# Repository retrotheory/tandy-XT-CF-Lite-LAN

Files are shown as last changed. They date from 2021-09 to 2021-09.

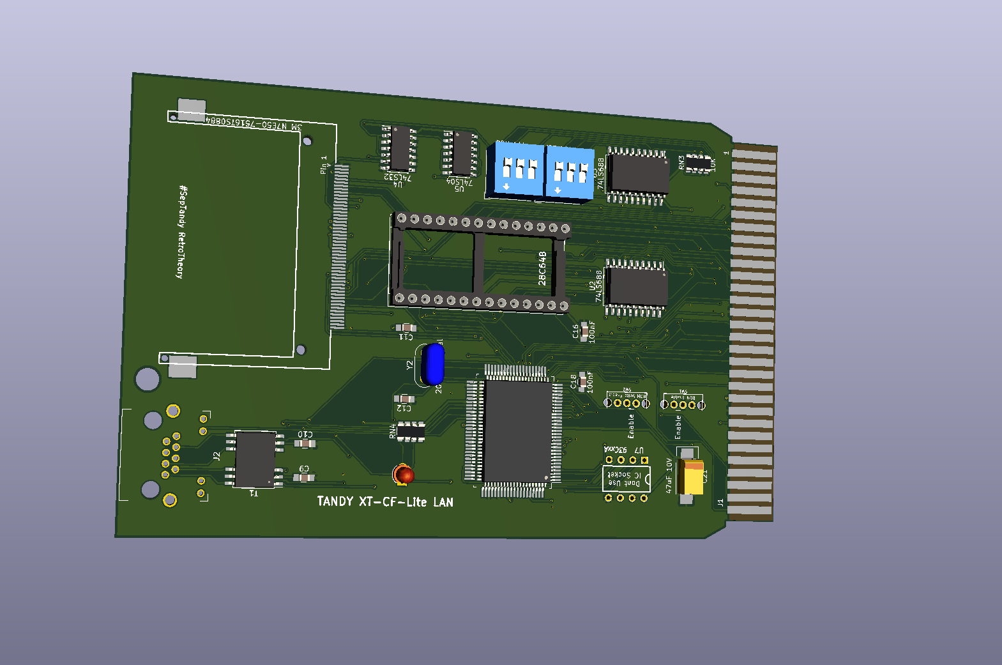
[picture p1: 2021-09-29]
Images/BoardRender.png

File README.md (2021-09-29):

Tandy XT-CF-Lite LAN Rev 0.9a ReadMe
----------------------------
This is a Compact Flash HD and Realtek LAN card for the Tandy 1400. It uses the expansion slot on the rear of the Tandy to add a bootable HD. 
The Realtek 8019AS is an NE2000 compatible. Uses the XT NE2000 packet driver. 

https://www.vcfed.org/forum/forum/genres/pcs-and-clones/41507-ne2000-packet-drivers-for-8-bit-slots

RSET8019.EXE for DOS, can set EEPROM parameters, also includes diagnostic functions

8-bit TANDY (ISA) CompactFlash interface + Boot ROM + LAN

Documentation for the switches can be found on the rear silkscreen. More ROM I/O addresses are possible than the information on the silkscreen. See below.

Credit:
-------
Design uses schematic from Sergey Kiselev, with a few small changes to switches, and PCB from scratch.\
www.malinov.com/Home/sergeys-projects/xt-cf-lite

https://www.lo-tech.co.uk/xt-cf-card-for-tandy-1400-series-laptops/
James Pearce for showing that this was possible a long long time ago.

XT-IDE Universal BIOS\
www.xtideuniversalbios.org  
www.xtideuniversalbios.org/binaries  
Use the latest working binary that includes XTIDECFG.COM (config utility), ide_xt.bin (8086/8088), ide_xtp.bin (80186/V20/V30 and up).

Further documentation:
----------------------

SW1 - ON: ROM Enabled; OFF: ROM Disabled\
SW2 - ON: EEPROM Write Enabled; OFF: EEPROM Write Disabled

---

SW3 - ROM I/O Port:  
123 ROM  
111 C0000  < Tandy Default  
110 C4000  
101 C8000  
101 CA000  
100 CC000  
011 D0000 
010 D4000  
001 D8000  
000 DC000  

Make sure that selected I/O and EEPROM addresses do not conflict with other devices.
Addresses 0xC0000 - 0xC6000 will conflict with EGA/VGA BIOS extension.
Addresses 0xC8000 - 0xCA000 might conflict with XT Hard Disk BIOS extension.
Addresses 0xE0000 and up might conflict with system BIOS on newer motherboards.
It is recommended to disable EEPROM write once XT IDE BIOS extension is programmed and configured.

---

SW4 - IDE I/O Port:  
123 IDE  
111 300 < Default  
011 320  
101 340  
001 360  
110 380  
010 3A0  
100 3C0  
000 3E0  

---

LAN 
Realtek 8019AS 93LC46 EEPROM
Due to height restrictions in the Tandy expansion bay, dont use an IC socket for the U7 93CXX   (93LC46)

---

| References | Value | Footprint | Quantity Per PCB |
|---|---|---|---|
| C1 C2 C3 C4 C5 C6 C15 C16 C17 C18 C19 | 100nF | C_0805_HandSoldering | 11 |
| C20 | 100nF | C_0805_HandSoldering | 1 |
| C7 C8 | 10uF | C_0805_HandSoldering | 2 |
| C21 | 47uF 10V | CP_Tantalum_Case-D_EIA-7343-31_Hand | 1 |
| C9 C10 C11 C12 C13 C14 | C | C_0805_HandSoldering | 6 |
| D1 | IDE LED | LED_D3.0mm | 1 |
| J2 | RJ45_LED_Shielded | 8P8C_yellow_green_Ckmtw_C133529 | 1 |
| J1 | Tandy_PCBEdgeBus_02x30 | Connector_PCBEdge_Tandy1400LT | 1 |
| P1 | CF_CARD | CF_Slot_3M_N7E50-7516TS0884 | 1 |
| P2 | IDE LED | PinHeader_1x02_P2.54mm_Horizontal | 1 |
| R3 | 200R | R_0805_HandSoldering | 1 |
| R5 R6 | 1K | R_0805_HandSoldering | 2 |
| R1 | 5.6k | C_0805_2012Metric_Pad1.15x1.40mm_HandSolder | 1 |
| R2 | 10K | C_0805_2012Metric_Pad1.15x1.40mm_HandSolder | 1 |
| R7 | 10K | R_0805_HandSoldering | 1 |
| R4 | 27k | R_0805_HandSoldering | 1 |
| RN1 RN2 RN3 | 10K | R_Array_Convex_4x1206 | 3 |
| RN4 | 1K | R_Array_Convex_4x1206 | 1 |
| SW4 | IDE Addr | SW_DIP_SPSTx03_Slide_9.78x9.8mm_W7.62mm_P2.54mm | 1 |
| SW3 | ROM Addr | SW_DIP_SPSTx03_Slide_9.78x9.8mm_W7.62mm_P2.54mm | 1 |
| SW1 | ROM Enable | CKCOMP-OS102011MA1QN1 | 1 |
| SW2 | ROM Write Enable | CKCOMP-OS102011MA1QN1 | 1 |
| T1 | 13F-39MNL | SOIC-16W-12_7.5x10.3mm_P1.27mm | 1 |
| U1 | 28C64 | DIP-28_W15.24mm_Socket | 1 |
| U5 | 74LS04 | SOIC-14_3.9x8.7mm_P1.27mm | 1 |
| U4 | 74LS32 | SOIC-14_3.9x8.7mm_P1.27mm | 1 |
| U2 U3 | 74LS688 | SOIC-20W_7.5x12.8mm_P1.27mm | 2 |
| U7 | 93CxxA | IC_DIP8_300 | 1 |
| U6 | RTL8019AS | LQFP-14x20mm_P0.5mmRealtek | 1 |
| Y2 | 20Mhz Crystal | Resonator-2pin_w8.0mm_h3.5mm | 1 |

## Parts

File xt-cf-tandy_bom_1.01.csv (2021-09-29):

Component | Description | Part | References | Value | Footprint | Quantity Per PCB | Datasheet
1 |  | C-xt-cf-rescue | C1 C2 C3 C4 C5 C6 C15 C16 C17 C18 C19 | 100nF | C_0805_HandSoldering | 11
2 | Unpolarized capacitor | C | C20 | 100nF | C_0805_HandSoldering | 1 | ~
3 |  | CP1-xt-cf-rescue | C7 C8 | 10uF | C_0805_HandSoldering | 2
4 | Unpolarized capacitor | C | C21 | 47uF 10V | CP_Tantalum_Case-D_EIA-7343-31_Hand | 1 | ~
5 | Unpolarized capacitor | C | C9 C10 C11 C12 C13 C14 | C | C_0805_HandSoldering | 6 | ~
6 | Light emitting diode | LED | D1 | IDE LED | LED_D3.0mm | 1
7 |  | RJ45_LED_Shielded | J2 | RJ45_LED_Shielded | 8P8C_yellow_green_Ckmtw_C133529 | 1
8 | Generic connector, single row, 01x30, script generated (kicad-library-utils/schlib/autogen/connector/) | Tandy_PCBEdgeBus_02x30 | J1 | Tandy_PCBEdgeBus_02x30 | Connector_PCBEdge_Tandy1400LT | 1 | ~
9 |  | CF_CARD-xt-cf-rescue | P1 | CF_CARD | CF_Slot_3M_N7E50-7516TS0884 | 1
10 |  | CONN_2-xt-cf-rescue | P2 | IDE LED | PinHeader_1x02_P2.54mm_Horizontal | 1
11 | Resistor | R | R3 | 200R | R_0805_HandSoldering | 1 | ~
12 | Resistor | R | R5 R6 | 1K | R_0805_HandSoldering | 2 | ~
13 |  | R-xt-cf-rescue | R1 | 5.6k | C_0805_2012Metric_Pad1.15x1.40mm_HandSolder | 1
14 |  | R-xt-cf-rescue | R2 | 10K | C_0805_2012Metric_Pad1.15x1.40mm_HandSolder | 1
15 | Resistor | R | R7 | 10K | R_0805_HandSoldering | 1 | ~
16 | Resistor | R | R4 | 27k | R_0805_HandSoldering | 1 | ~
17 | 4 resistor network, parallel topology | R_Pack04 | RN1 RN2 RN3 | 10K | R_Array_Convex_4x1206 | 3 | ~
18 | 4 resistor network, parallel topology | R_Pack04 | RN4 | 1K | R_Array_Convex_4x1206 | 1 | ~
19 | 3x DIP Switch, Single Pole Single Throw (SPST) switch, small symbol | SW_DIP_x03 | SW4 | IDE Addr | SW_DIP_SPSTx03_Slide_9.78x9.8mm_W7.62mm_P2.54mm | 1
20 | 3x DIP Switch, Single Pole Single Throw (SPST) switch, small symbol | SW_DIP_x03 | SW3 | ROM Addr | SW_DIP_SPSTx03_Slide_9.78x9.8mm_W7.62mm_P2.54mm | 1
21 | Switch, single pole double throw | SW_SPDT | SW1 | ROM Enable | CKCOMP-OS102011MA1QN1 | 1
22 | Switch, single pole double throw | SW_SPDT | SW2 | ROM Write Enable | CKCOMP-OS102011MA1QN1 | 1
23 |  | 13F-39MNL | T1 | 13F-39MNL | SOIC-16W-12_7.5x10.3mm_P1.27mm | 1
24 |  | 28C64-xt-cf-rescue | U1 | 28C64 | DIP-28_W15.24mm_Socket | 1
25 |  | 74LS04-xt-cf-rescue | U5 | 74LS04 | SOIC-14_3.9x8.7mm_P1.27mm | 1
26 |  | 74LS32-xt-cf-rescue | U4 | 74LS32 | SOIC-14_3.9x8.7mm_P1.27mm | 1
27 |  | 74LS688-xt-cf-rescue | U2 U3 | 74LS688 | SOIC-20W_7.5x12.8mm_P1.27mm | 2
28 | Serial EEPROM, 93 Series, 5.0V, DIP-8/SOIC-8 | 93CxxA | U7 | 93CxxA | IC_DIP8_300 | 1 | http://ww1.microchip.com/downloads/en/DeviceDoc/20001749K.pdf
29 |  | RTL8019AS | U6 | RTL8019AS | LQFP-14x20mm_P0.5mmRealtek | 1
30 | Two pin crystal | Crystal | Y2 | 20Mhz Crystal | Resonator-2pin_w8.0mm_h3.5mm | 1 | ~
Component Groups: | 30
Component Count: | 50
Fitted Components: | 50
Number of PCBs: | 1
Total components: | 50
Schematic Version: | 1.01
Schematic Date: | 2021-09-29
PCB Variant: | default
BoM Date: | 29/09/2021 14:19:13
Schematic Source: | xt-cf-tandy.sch
KiCad Version: | Eeschema (5.1.6)-1

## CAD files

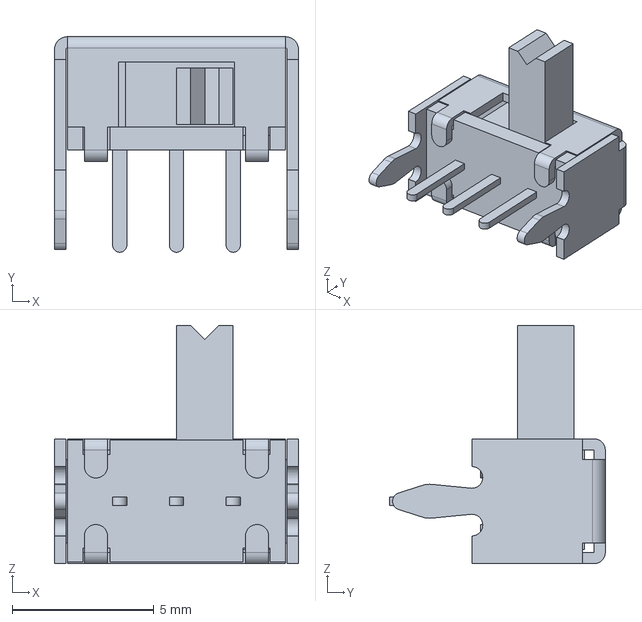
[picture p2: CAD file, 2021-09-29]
3Dmodels/OS102011MA1QN1.stp
8.60 x 7.60 x 8.40 mm

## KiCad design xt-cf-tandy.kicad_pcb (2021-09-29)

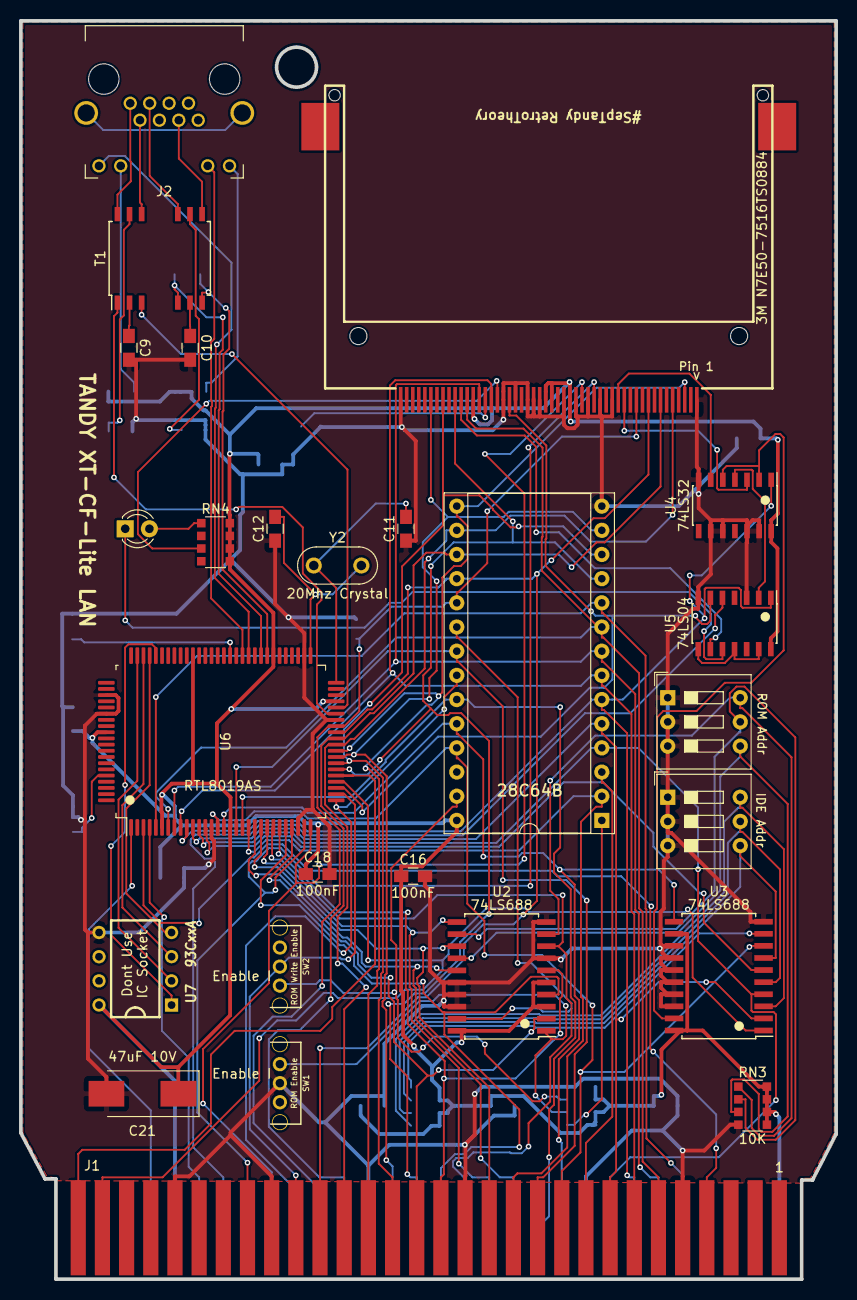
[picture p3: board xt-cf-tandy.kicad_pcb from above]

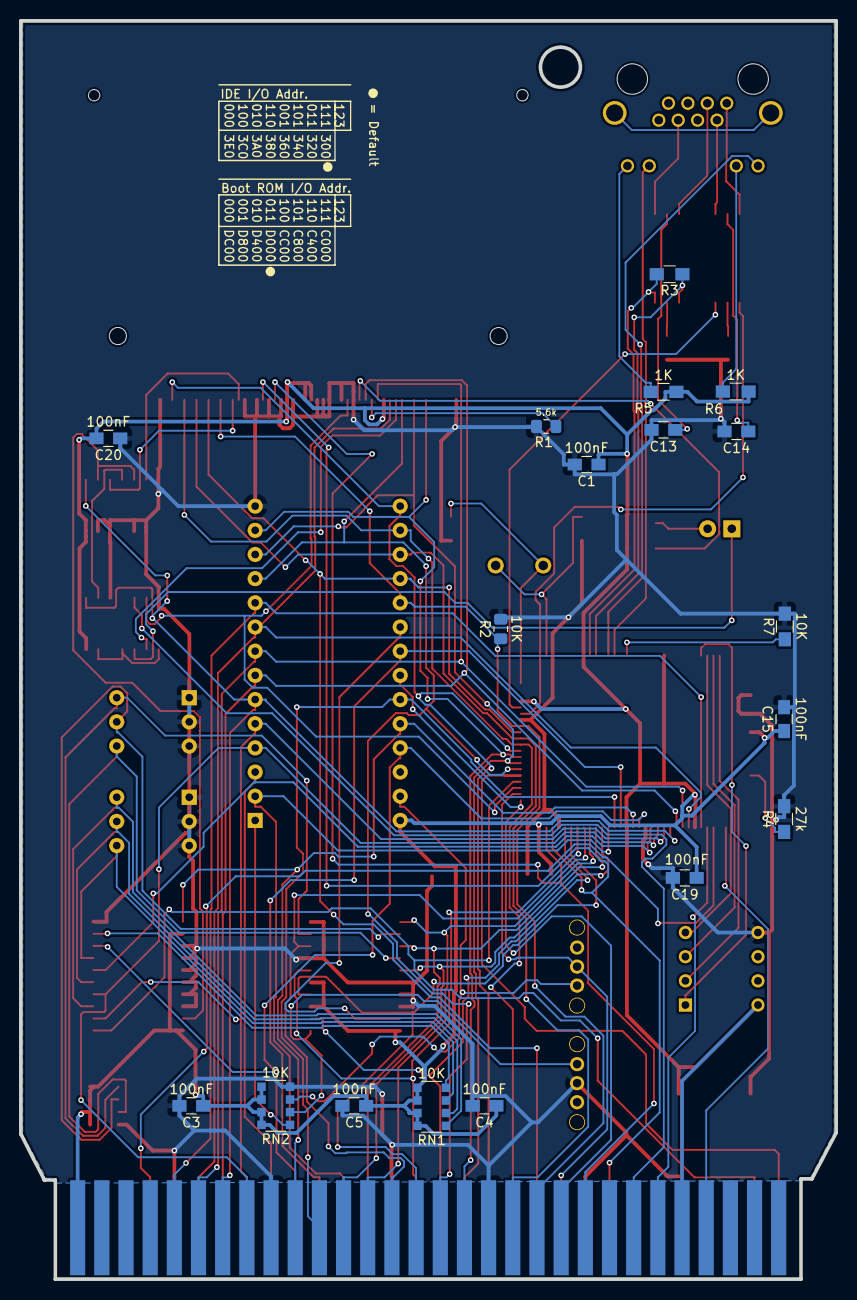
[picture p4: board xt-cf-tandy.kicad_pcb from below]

Board: 2 copper layers, 85.7 x 132.2 mm, 44 parts (18 on the bottom side), 86 nets.

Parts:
C1, C3, C4, C5, C15, C16, C18, C19, C20: 100nF; C_0805_HandSoldering
C9, C10, C11, C12, C13, C14: C; C_0805_HandSoldering
C21: 47uF 10V; CP_Tantalum_Case-D_EIA-7343-31_Hand
D1: IDE LED; LED_D3.0mm
J1: Tandy_PCBEdgeBus_02x30; Connector_PCBEdge_Tandy1400LT
J2: RJ45_LED_Shielded; 8P8C_yellow_green_Ckmtw_C133529
P1: CF_CARD; CF_Slot_3M_N7E50-7516TS0884
R1: 5.6k; C_0805_2012Metric_Pad1.15x1.40mm_HandSolder
R2: 10K; C_0805_2012Metric_Pad1.15x1.40mm_HandSolder
R3: 200R; R_0805_HandSoldering
R4: 27k; R_0805_HandSoldering
R5, R6: 1K; R_0805_HandSoldering
R7: 10K; R_0805_HandSoldering
RN1, RN2, RN3: 10K; R_Array_Convex_4x1206
RN4: 1K; R_Array_Convex_4x1206
SW1: ROM Enable; CKCOMP-OS102011MA1QN1
SW2: ROM Write Enable; CKCOMP-OS102011MA1QN1
SW3: ROM Addr; SW_DIP_SPSTx03_Slide_9.78x9.8mm_W7.62mm_P2.54mm
SW4: IDE Addr; SW_DIP_SPSTx03_Slide_9.78x9.8mm_W7.62mm_P2.54mm
T1: 13F-39MNL; SOIC-16W-12_7.5x10.3mm_P1.27mm
U1: 28C64; DIP-28_W15.24mm_Socket
U2, U3: 74LS688; SOIC-20W_7.5x12.8mm_P1.27mm
U4: 74LS32; SOIC-14_3.9x8.7mm_P1.27mm
U5: 74LS04; SOIC-14_3.9x8.7mm_P1.27mm
U6: RTL8019AS; LQFP-14x20mm_P0.5mmRealtek
U7: 93CxxA; IC_DIP8_300
Y2: 20Mhz Crystal; Resonator-2pin_w8.0mm_h3.5mm

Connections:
/A0: J1.10, U1.10, U6.5
/A1: J1.11, P1.20, U1.9, U6.7
/A2: J1.12, P1.19, U1.8, U6.8
/A3: J1.13, P1.18, U1.7, U6.9
/A4: J1.14, U1.6, U4.1, U5.1, U6.10
/A5: J1.15, U1.5, U3.2, U6.11
/A6: J1.16, U1.4, U3.4, U6.12
/A7: J1.17, U1.3, U3.6, U6.13
/A8: J1.19, U1.25, U3.8, U6.15
/A9: J1.20, U1.24, U3.11, U6.16
/A10: J1.21, U1.21, U6.18
/A11: J1.22, U1.23, U6.19
/A12: J1.23, U1.2, U6.20
/A13: J1.24, U2.15, U6.21
/A14: J1.25, U2.13, U6.22
/A15: J1.26, U2.11, U6.23
/A16: J1.28, U2.8, U6.24
/A17: J1.29, U2.6, U6.25
/A18: J1.30, U2.4, U6.26
/A19: J1.31, U2.2, U6.27
/AEN: J1.57, U3.1, U6.34
/CF_DMARQ: P1.43, R1.1
/CF_IORDY: P1.42, RN4.3
/D0: J1.32, P1.21, U1.11, U6.36
/D1: J1.33, P1.22, U1.12, U6.37
/D2: J1.34, P1.23, U1.13, U6.38
/D3: J1.35, P1.2, U1.15, U6.39
/D4: J1.37, P1.3, U1.16, U6.40
/D5: J1.38, P1.4, U1.17, U6.41
/D6: J1.39, P1.5, U1.18, U6.42
/D7: J1.40, P1.6, R2.1, U1.19, U6.43
/IO_READY: J1.59, U6.35
/IRQ2: J1.50, U6.4
/IRQ3: J1.7, U6.3
/IRQ5: J1.54, U6.1
/LED0: J2.9, U6.61
/LED1: J2.11, U6.62
/NX1: C11.2, U6.50, Y2.1
/NX2: C12.2, U6.51, Y2.2
/RDY/~BUSY: RN2.1, U1.1
/RESET: P1.41, U5.6, U6.33
/TPIN+: R3.1, T1.6, U6.59
/TPIN-: R3.2, T1.8, U6.58
/TPOUT+: T1.1, U6.45
/TPOUT-: T1.3, U6.46
/~BRST: J1.48, U5.5
/~CF_CS0: P1.7, U4.3
/~CF_CS1: P1.32, U4.6
/~CF_DASP: P1.45, U5.9
/~IOR: J1.45, P1.34, U6.29
/~IOW: J1.44, P1.35, U6.30
/~MEMR: J1.42, U1.22, U6.31
/~MEMW: J1.41, SW2.2, U6.32
/~ROMW: RN2.3, SW2.3, U1.27
/~ROM_CS: U1.20, U2.19
GND: C1.2, C3.2, C4.2, C5.2, C9.2, C10.2, C11.1, C12.1, C13.2, C14.2, C15.2, C16.2, C18.2, C19.2, C20.1, C21.2, J1.9, J1.18, J1.27, J1.36, J1.43, J1.51, P1.1, P1.8, P1.9, P1.10, P1.11, P1.12, P1.14, P1.15, P1.16, P1.17, P1.39, P1.50, R1.2, R2.2, R4.2, R7.2, RN2.4, RN3.4, SW1.2, SW3.1, SW3.2, SW3.3, SW4.1, SW4.2, SW4.3, U1.14, U2.7, U2.10, U2.16, U2.17, U2.18, U3.10, U3.13, U3.14, U3.15, U3.16, U3.17, U3.18, U4.7, U4.9, U4.10, U4.12, U4.13, U5.3, U5.7, U6.14, U6.28, U6.44, U6.52, U6.83, U6.86, U7.5
unnamed: C9.1, T1.2
unnamed: C10.1, T1.7
unnamed: C13.1, T1.10
unnamed: C14.1, T1.15
unnamed: D1.1, U5.10
unnamed: D1.2, RN4.1
unnamed: J2.1, T1.16
unnamed: J2.2, T1.14
unnamed: J2.3, T1.11
unnamed: J2.6, T1.9
unnamed: J2.10, R6.2
unnamed: J2.12, R5.2
unnamed: R4.1, U6.96
unnamed: R7.1, U6.64
unnamed: RN1.1, SW4.6, U3.3
unnamed: RN1.2, SW4.5, U3.5
unnamed: RN1.3, SW4.4, U3.7
unnamed: RN1.4, U3.9
unnamed: RN2.2, SW1.1, U2.1
unnamed: RN3.1, SW3.6, U2.9
unnamed: RN3.2, SW3.5, U2.12
unnamed: RN3.3, SW3.4, U2.14
unnamed: U3.19, U4.2, U4.5
unnamed: U4.4, U5.2
unnamed: U5.8, U5.11, U5.13
unnamed: U6.76, U7.1
unnamed: U6.77, U7.4
unnamed: U6.78, U7.3
unnamed: U6.79, U7.2
VCC: C1.1, C3.1, C4.1, C5.1, C15.1, C16.1, C18.1, C19.1, C20.2, C21.1, J1.2, J1.52, P1.13, P1.36, P1.38, P1.44, R5.1, R6.1, RN1.5, RN1.6, RN1.7, RN1.8, RN2.5, RN2.6, RN2.7, RN2.8, RN3.5, RN3.6, RN3.7, RN3.8, RN4.5, RN4.6, RN4.7, RN4.8, U1.28, U2.3, U2.5, U2.20, U3.12, U3.20, U4.14, U5.14, U6.6, U6.17, U6.47, U6.57, U6.70, U6.89, U7.8
